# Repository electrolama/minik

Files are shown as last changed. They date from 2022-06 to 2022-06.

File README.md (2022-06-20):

# minik

A tiny RP2040 module for small embedded things!

minik is designed by Electrolama / @omerk and licensed under the Solderpad Hardware License 2.0.

## Status

module design files are already in this repo, breakout and libraries to follow. [Here's a preview](https://twitter.com/OmerK/status/1535297431444791298) of what the module and breakout looks like.

## CircuitPython support

minik is supported by CircuitPython! Grab the latest builds [here](https://adafruit-circuit-python.s3.amazonaws.com/index.html?prefix=bin/electrolama_minik).

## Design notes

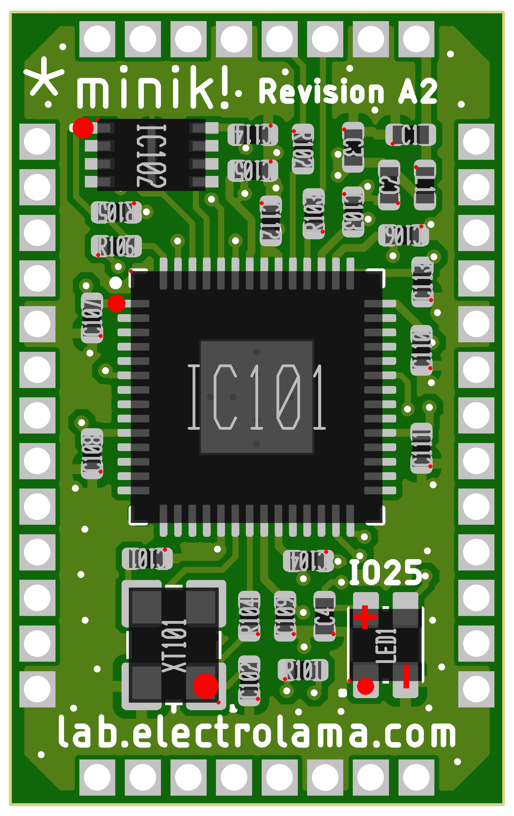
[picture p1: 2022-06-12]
module/Revision A2/prod/minik-RevA2-placement.png

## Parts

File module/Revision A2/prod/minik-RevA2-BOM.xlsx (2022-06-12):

Comment | Designator | Footprint | JLCPCB Part # | Manufacturer | MPN | Qty
 | L1 | _PKG_L_0402 | C21516 | Murata Electronics | BLM15HD102SN1D | 1
12MHz | XT101 | 3.2X2.5_KX-7 | C97242 | TXC Corp | 7V12000018 | 1
100n | C2, C4, C104, C105, C107, C108, C109, C110, C111, C112, C113, C114 | _PKG_C_0402 | C1525 | Samsung Electro-Mechanics | CL05B104KO5NNNC | 12
10k | R101, R105 | _PKG_R_0402 | C25744 | UNI-ROYAL(Uniroyal Elec) | 0402WGF1002TCE | 2
10n | C1 | _PKG_C_0402 | C15195 | Samsung Electro-Mechanics | CL05B103KB5NNNC | 1
10u | C3 | _PKG_C_0402 | C15525 | Samsung Electro-Mechanics | CL05A106MQ5NUNC | 1
12p | C101, C102 | _PKG_C_0402 | C1547 | FH(Guangdong Fenghua Advanced Tech) | 0402CG120J500NT | 2
1k | R104, R106 | _PKG_R_0402 | C11702 | UNI-ROYAL(Uniroyal Elec) | 0402WGF1001TCE | 2
1u | C103, C106 | _PKG_C_0402 | C52923 | Samsung Electro-Mechanics | CL05A105KA5NQNC | 2
27 | R102, R103 | _PKG_R_0402 | C25100 | UNI-ROYAL(Uniroyal Elec) | 0402WGF270JTCE | 2
MEMORY-W25Q16FWUXIE | IC102 | SON50P300X200X60-9N | C401672 | Winbond Elec | W25Q16FWUXIE | 1
RP2040 | IC101 | QFN-56 | C2040 | Raspberry Pi | RP2040 | 1
WS2812C-2020-V1 | LED1 | WS2812B-2020 | C2976072 | Worldsemi | WS2812C-2020-V1 | 1

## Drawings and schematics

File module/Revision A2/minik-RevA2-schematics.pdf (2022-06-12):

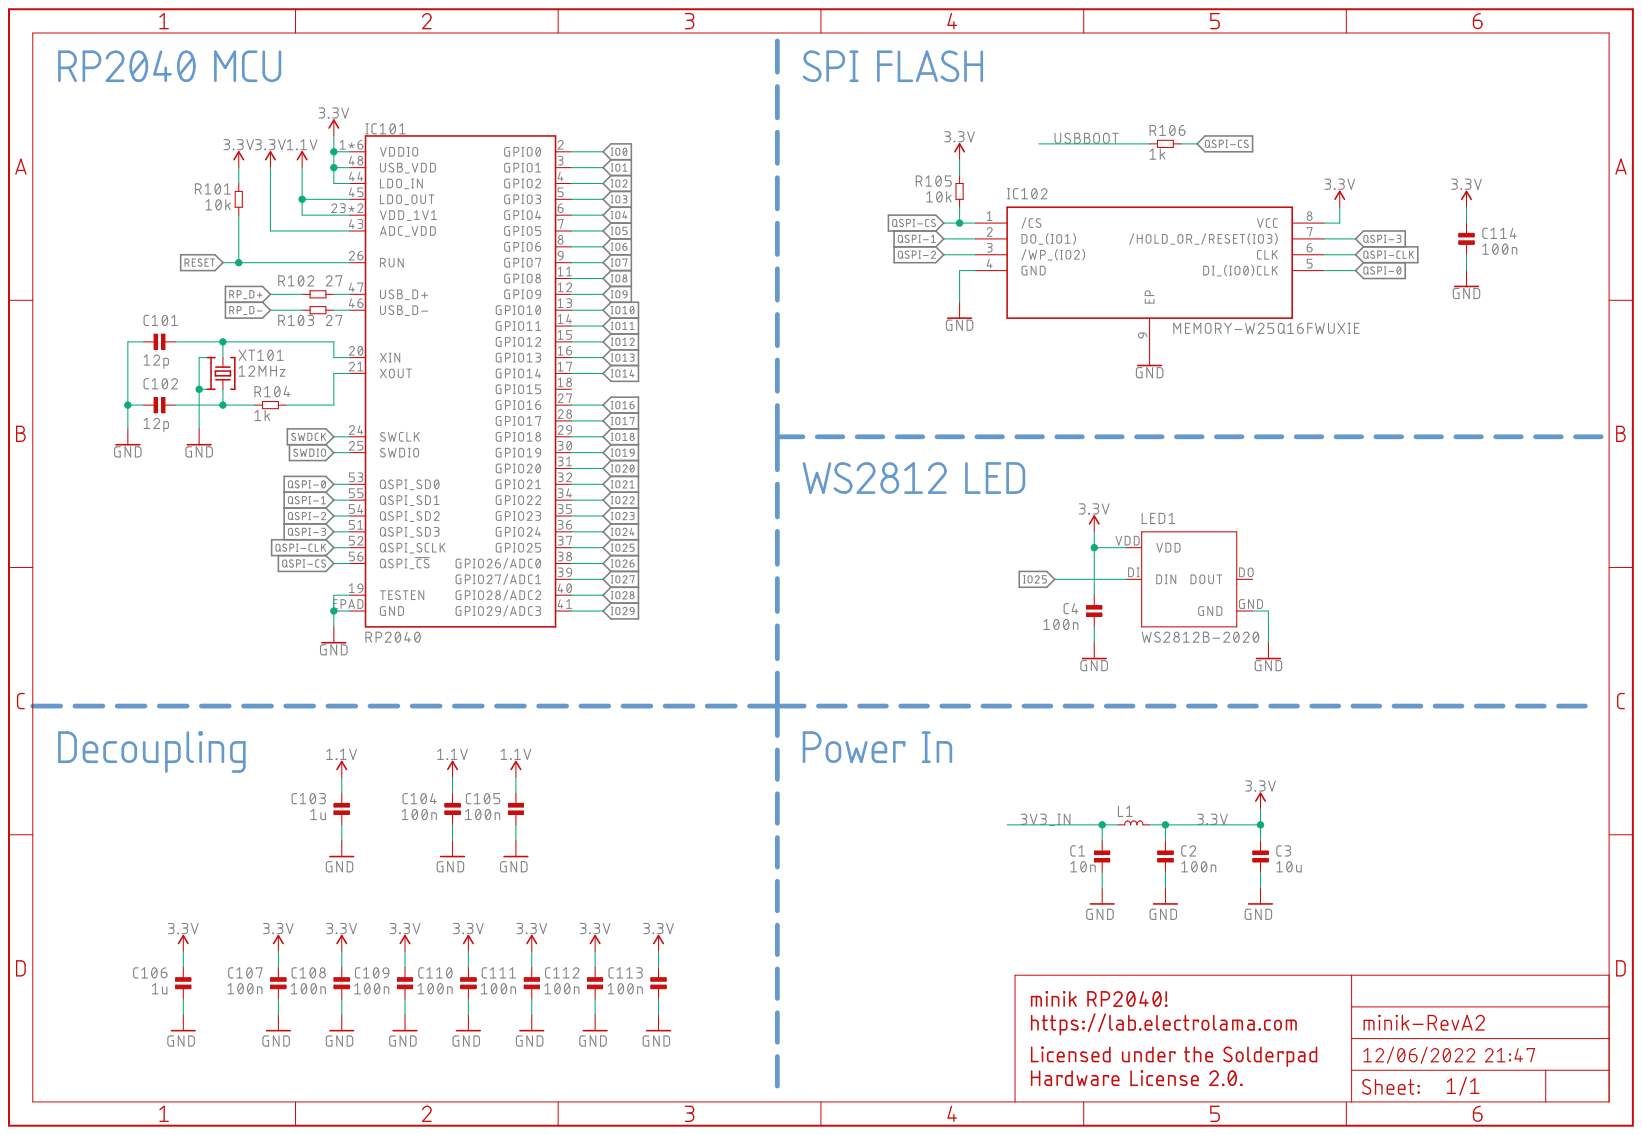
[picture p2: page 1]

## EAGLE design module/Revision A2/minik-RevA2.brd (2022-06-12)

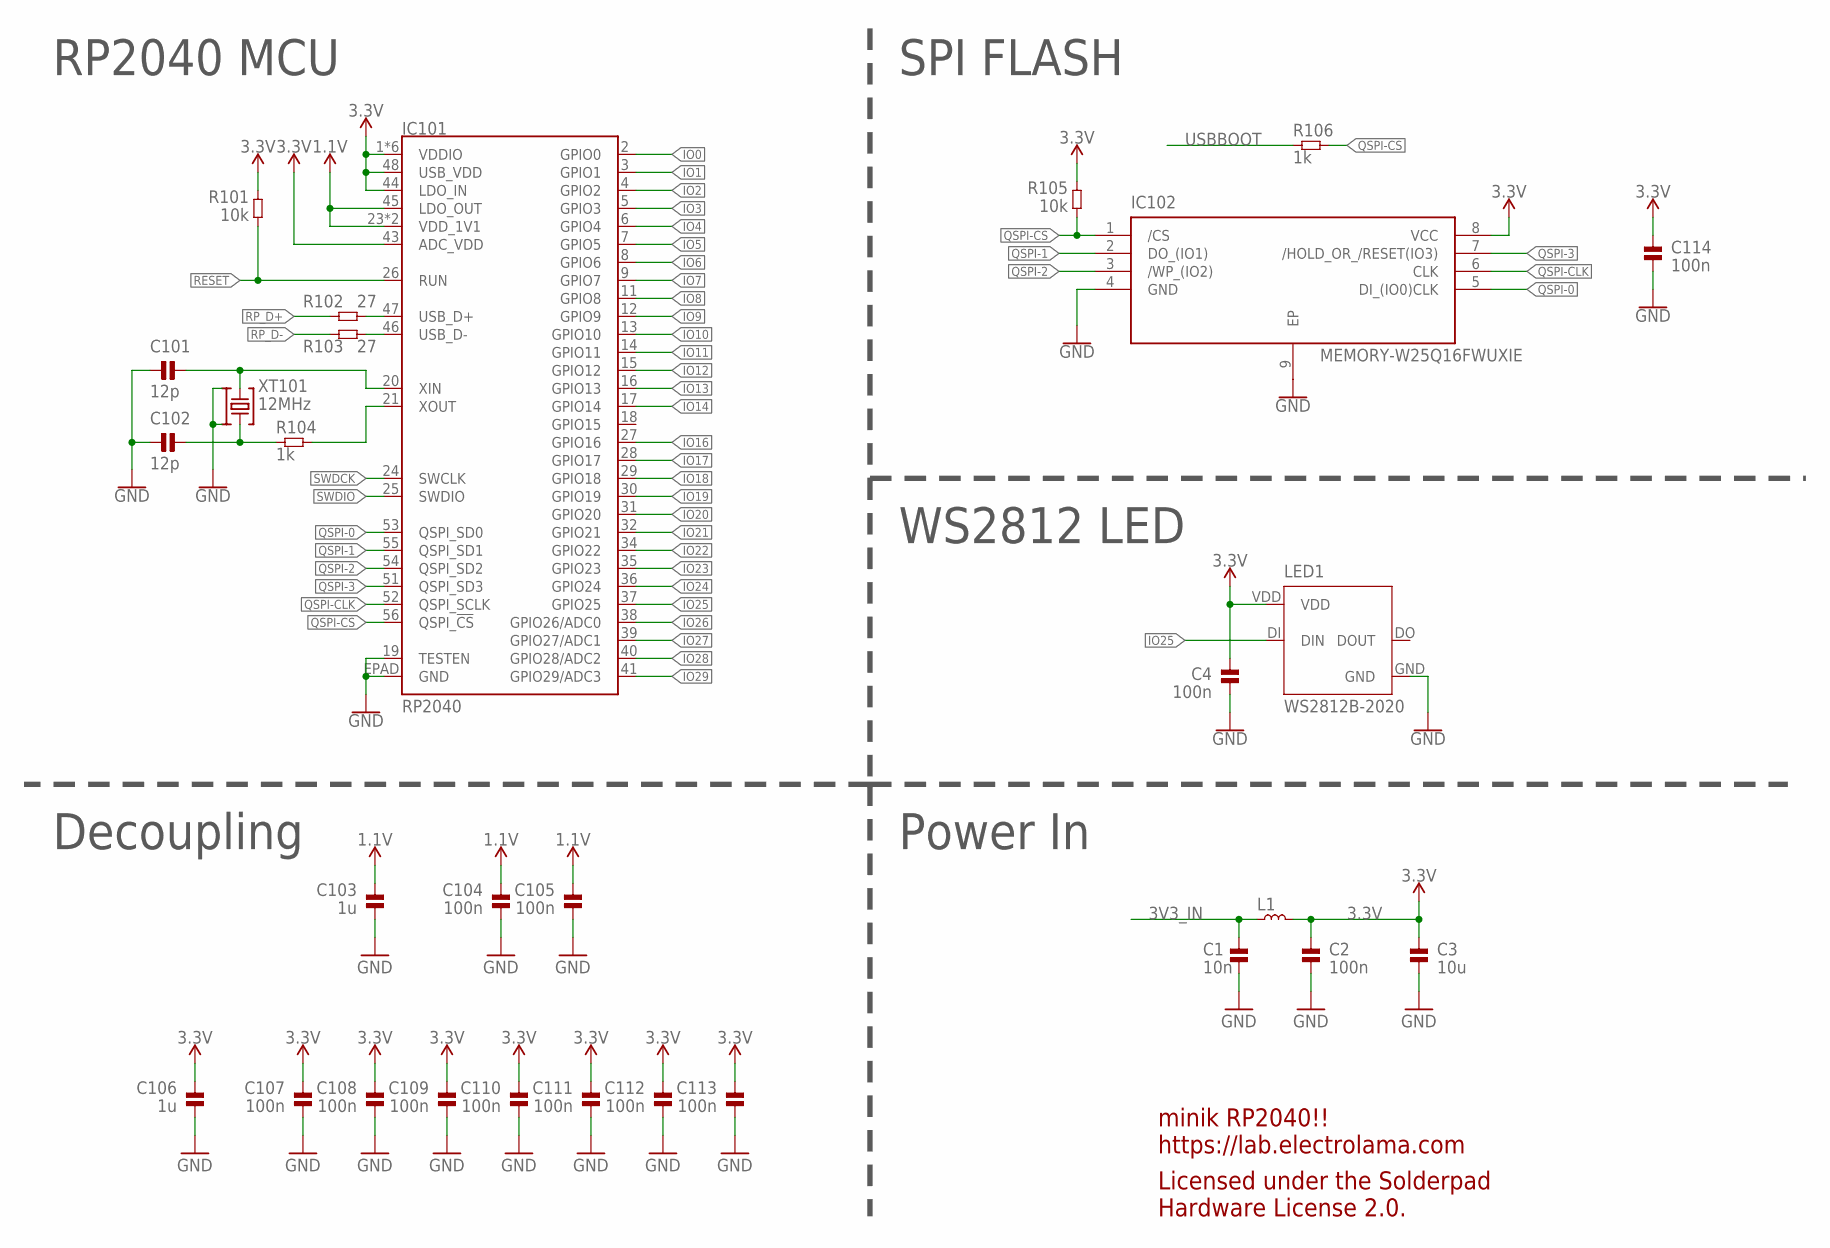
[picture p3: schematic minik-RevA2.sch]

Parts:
C1: 10n; _PKG_C_0402
C2, C4, C104, C105, C107, C108, C109, C110, C111, C112, C113, C114: 100n; _PKG_C_0402
C3: 10u; _PKG_C_0402
C101, C102: 12p; _PKG_C_0402
C103, C106: 1u; _PKG_C_0402
IC101: RP2040; QFN-56
IC102: MEMORY-W25Q16FWUXIE; SON50P300X200X60-9N
L1: INDUCTOR-0402; _PKG_L_0402
LED1: WS2812B-2020
R101, R105: 10k; _PKG_R_0402
R102, R103: 27; _PKG_R_0402
R104, R106: 1k; _PKG_R_0402
XT101: 12MHz; XTAL-4P-3225

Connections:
1.1V: C103.2, C104.2, C105.2, IC101.23 (VDD_1V1), IC101.45 (LDO_OUT), IC101.50 (VDD_1V1)
3.3V: C2.2, C3.2, C4.2, C106.2, C107.2, C108.2, C109.2, C110.2, C111.2, C112.2, C113.2, C114.2, IC101.1 (VDDIO), IC101.10 (VDDIO), IC101.22 (VDDIO), IC101.33 (VDDIO), IC101.42 (VDDIO), IC101.43 (ADC_VDD), IC101.44 (LDO_IN), IC101.48 (USB_VDD), IC101.49 (VDDIO), IC102.8 (VCC), L1.2, LED1.VDD, R101.2, R105.2
3V3_IN: C1.2, L1.1
GND: C1.1, C2.1, C3.1, C4.1, C101.1, C102.1, C103.1, C104.1, C105.1, C106.1, C107.1, C108.1, C109.1, C110.1, C111.1, C112.1, C113.1, C114.1, IC101.19 (TESTEN), IC101.EPAD (GND), IC102.4 (GND), IC102.9 (EP), LED1.GND, XT101.2, XT101.4
IO0: IC101.2 (GPIO0)
IO1: IC101.3 (GPIO1)
IO2: IC101.4 (GPIO2)
IO3: IC101.5 (GPIO3)
IO4: IC101.6 (GPIO4)
IO5: IC101.7 (GPIO5)
IO6: IC101.8 (GPIO6)
IO7: IC101.9 (GPIO7)
IO8: IC101.11 (GPIO8)
IO9: IC101.12 (GPIO9)
IO10: IC101.13 (GPIO10)
IO11: IC101.14 (GPIO11)
IO12: IC101.15 (GPIO12)
IO13: IC101.16 (GPIO13)
IO14: IC101.17 (GPIO14)
IO16: IC101.27 (GPIO16)
IO17: IC101.28 (GPIO17)
IO18: IC101.29 (GPIO18)
IO19: IC101.30 (GPIO19)
IO20: IC101.31 (GPIO20)
IO21: IC101.32 (GPIO21)
IO22: IC101.34 (GPIO22)
IO23: IC101.35 (GPIO23)
IO24: IC101.36 (GPIO24)
IO25: IC101.37 (GPIO25), LED1.DI (DIN)
IO26: IC101.38 (GPIO26/ADC0)
IO27: IC101.39 (GPIO27/ADC1)
IO28: IC101.40 (GPIO28/ADC2)
IO29: IC101.41 (GPIO29/ADC3)
unnamed: IC101.47 (USB_D+), R102.2
unnamed: IC101.46 (USB_D-), R103.2
QSPI-0: IC101.53 (QSPI_SD0), IC102.5 (DI_(IO0)CLK)
QSPI-1: IC101.55 (QSPI_SD1), IC102.2 (DO_(IO1))
QSPI-2: IC101.54 (QSPI_SD2), IC102.3 (/WP_(IO2))
QSPI-3: IC101.51 (QSPI_SD3), IC102.7 (/HOLD_OR_/RESET(IO3))
QSPI-CLK: IC101.52 (QSPI_SCLK), IC102.6 (CLK)
QSPI-CS: IC101.56 (QSPI_!CS!), IC102.1 (/CS), R105.1, R106.1
RESET: IC101.26 (RUN), R101.1
RP_D+: R102.1
RP_D-: R103.1
SWDCK: IC101.24 (SWCLK)
SWDIO: IC101.25 (SWDIO)
USBBOOT: R106.2
X1A: IC101.21 (XOUT), R104.2
X1B: C102.2, R104.1, XT101.1
X2: C101.2, IC101.20 (XIN), XT101.3

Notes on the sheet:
RP2040 MCU
SPI FLASH
WS2812 LED
Power In
Decoupling
minik RP2040!! https://lab.electrolama.com
Licensed under the Solderpad Hardware License 2.0.

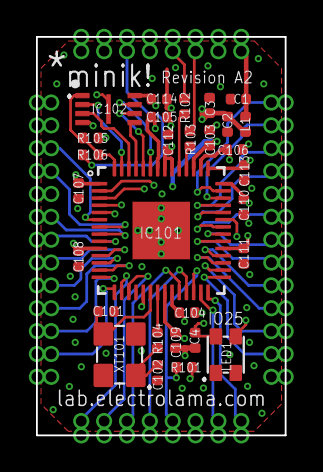
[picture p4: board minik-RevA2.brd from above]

Board: 4 copper layers, 13.8 x 22.1 mm, 29 parts (0 on the bottom side), 17 nets.

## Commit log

2022-06-12 minik module RevA2 sources and schematics PDF
    [minik-RevA2.brd, minik-RevA2.sch]
2022-06-12 minik module RevA2 production files
    [minik-RevA2-BOM.xlsx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]
2022-06-15 update status and preliminary circuitpython info
2022-06-20 update circuitpython info

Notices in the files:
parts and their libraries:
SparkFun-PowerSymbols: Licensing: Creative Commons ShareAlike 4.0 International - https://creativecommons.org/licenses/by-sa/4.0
